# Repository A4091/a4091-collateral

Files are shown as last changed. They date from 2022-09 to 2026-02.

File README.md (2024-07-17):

# A4091 collateral material

This repository contains all the artsy and non-PCB/non-logic/non-software
pieces that went into making the ReAmiga 4091:

## The Box

The original box dimensions are:

| Length | Width | Height |
|---|---|---|
| 43cm | 16cm  | 6.5cm  |
| 16.92" | 6.3"  | 2.56"  |

At least one DKB box out there was confirmed with these dimensions:

| Length | Width | Height |
|---|---|---|
| 39cm | 17cm  | 5cm |

You can find the art work in the `box/` subdirectory. *NOTE:* The first batch
of boxes we had manufactured were 17" x 6.75" x 3.25" as we did not have any
exact measurements to go by.

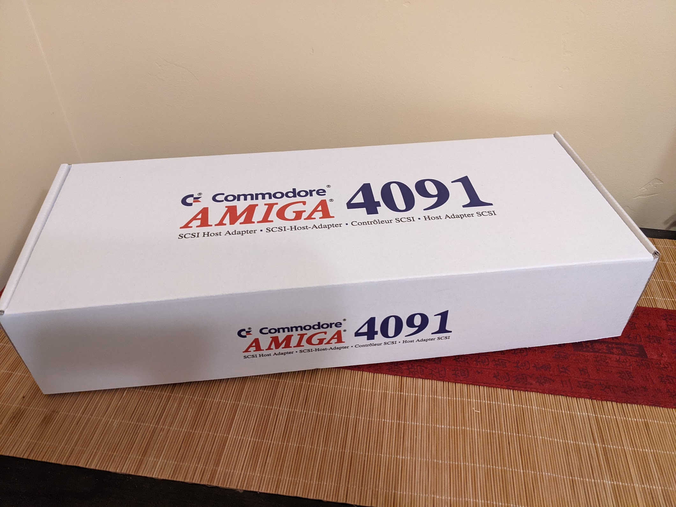
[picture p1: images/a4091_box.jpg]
Box

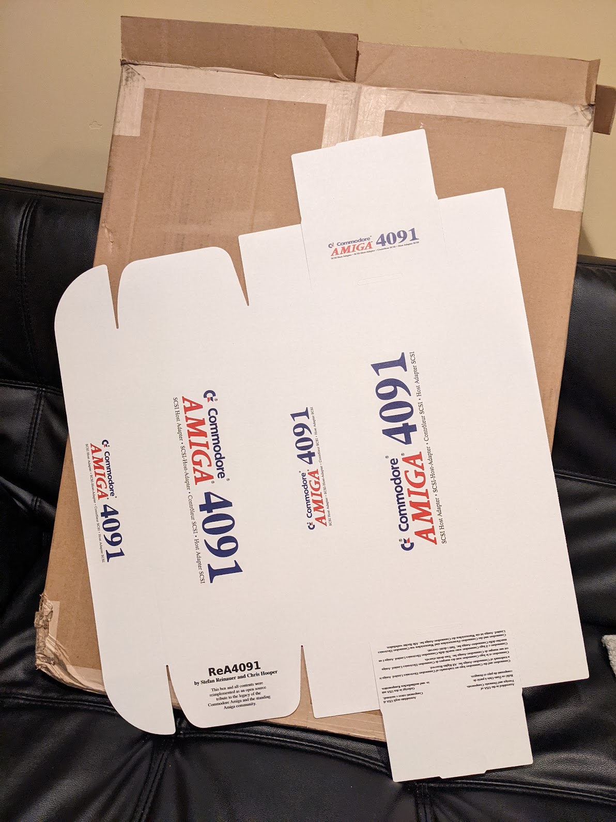
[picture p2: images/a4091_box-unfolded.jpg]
Box Unfolded


## The Manual

The A4091 manual is 5.5" x 7.75" in size. If you get it professionally printed,
it is recommended to use the English only version to keep costs down. If you
are going to print all languages, you will probably need to choose Perfect
bound instead of Stapled bound.

Recommended configuration:
- Size: W: 5.5" H: 7.75"
- Grayscale
- 80lb Satin paper
- 24+4 pages
- Binding: Staple
- Cover: 110lb Satin paper
- Cover: Color
- Cover: Soft Touch Lamination

## Bracket

The metal bracket was designed by Szymon Gosk.

It is recommended to laser cut the bracket, but you will need the appropriate
equipment to perform the narrow dual bend that prevents the metal from making
contact with the connectors on the back of the card. Additionally it is
recommended to apply some foil into the double bend.

Feel free to [contact us](mailto:a4091@amiga.technology) if you need a bracket.
We might still have some left.

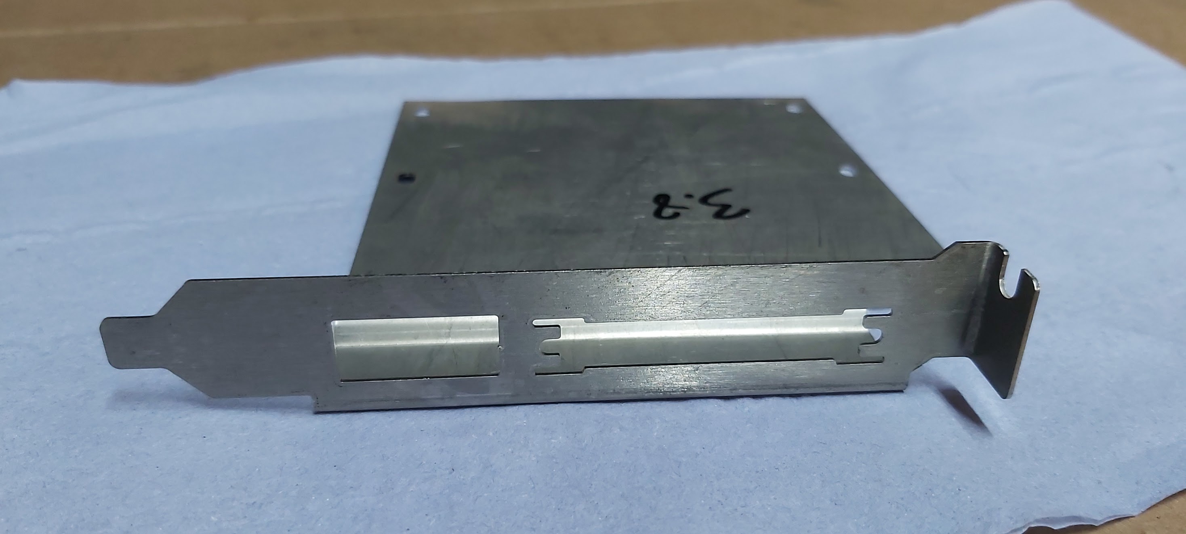
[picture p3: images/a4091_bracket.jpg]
Bracket


## Disk Labels

While the disk content is part of the a4091-software package, you can find a
set of disk labels here.

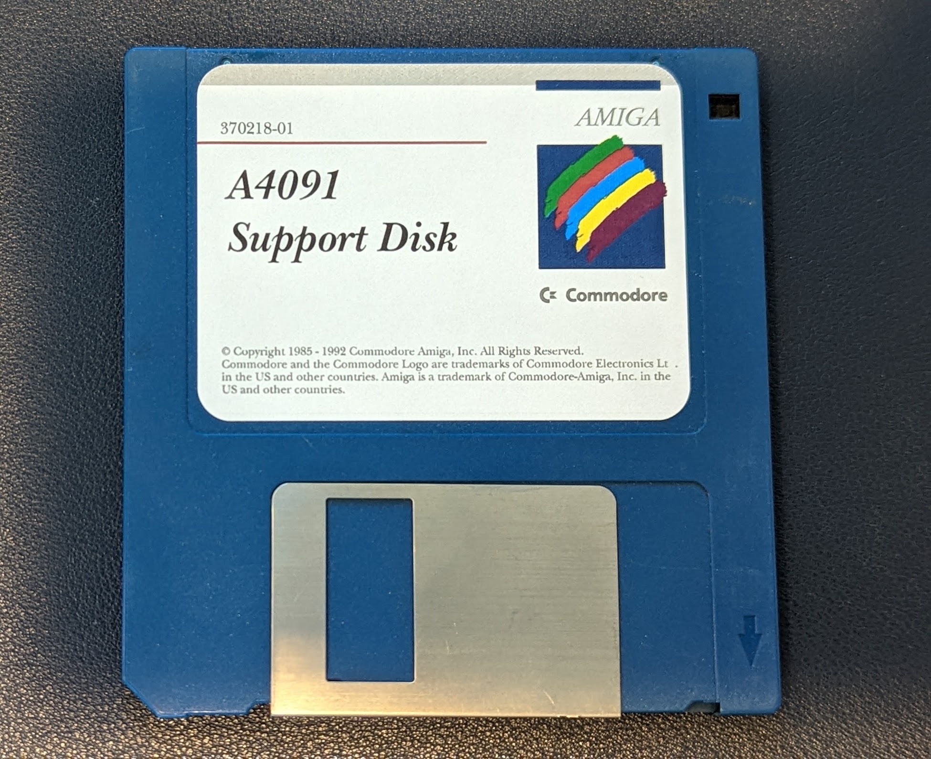
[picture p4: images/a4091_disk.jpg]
Disk


## Amiga 3000 LED adapter

A small adapter that lets you connect your A4091 to your A3000 LEDs. Gerbers
and KiCAD files included.

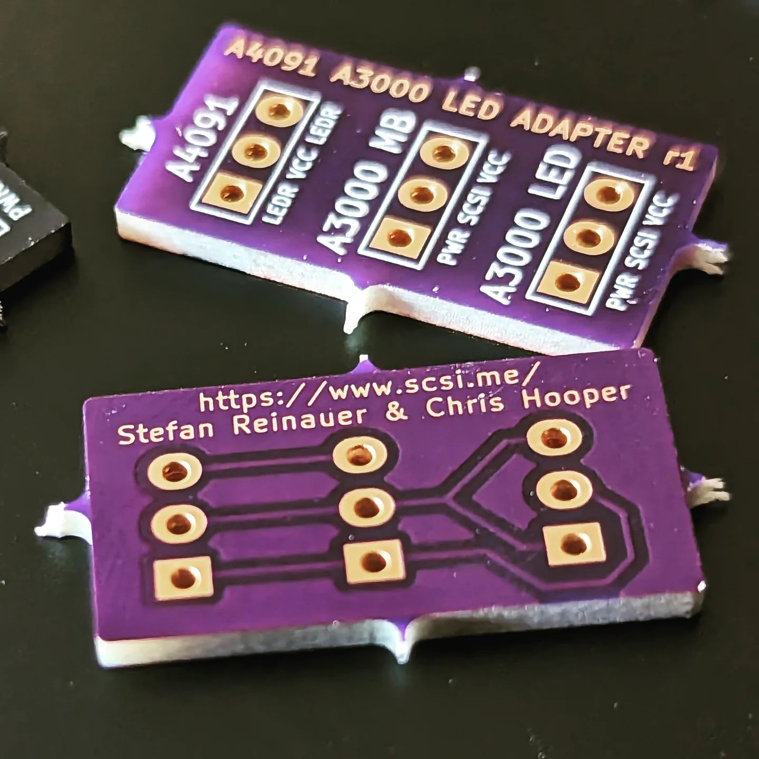
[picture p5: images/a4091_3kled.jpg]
LED adapter


## Miscellaneous

There are a couple of 3d-printable designs available to accompany the A4091
SCSI controller.

- An enclosure for the A4091 Terminator. This enclosure comes in two versions,
  Version v1 is optimized for printing on an FDM printer as the text on the lid
  is recessed. Version v2 has embossed text and is better printed on a Resin
  printer.

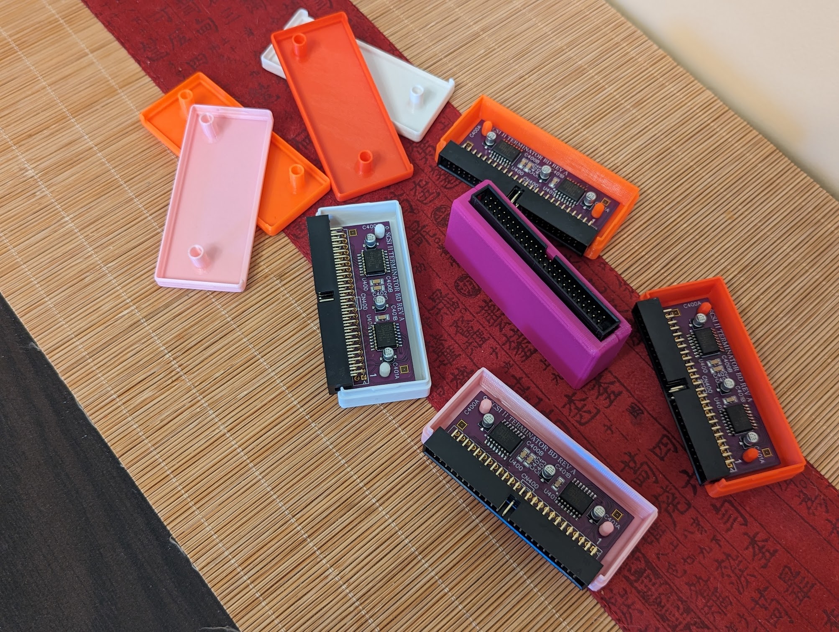
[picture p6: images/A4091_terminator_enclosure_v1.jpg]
A4091 Terminator enclosure v1
  
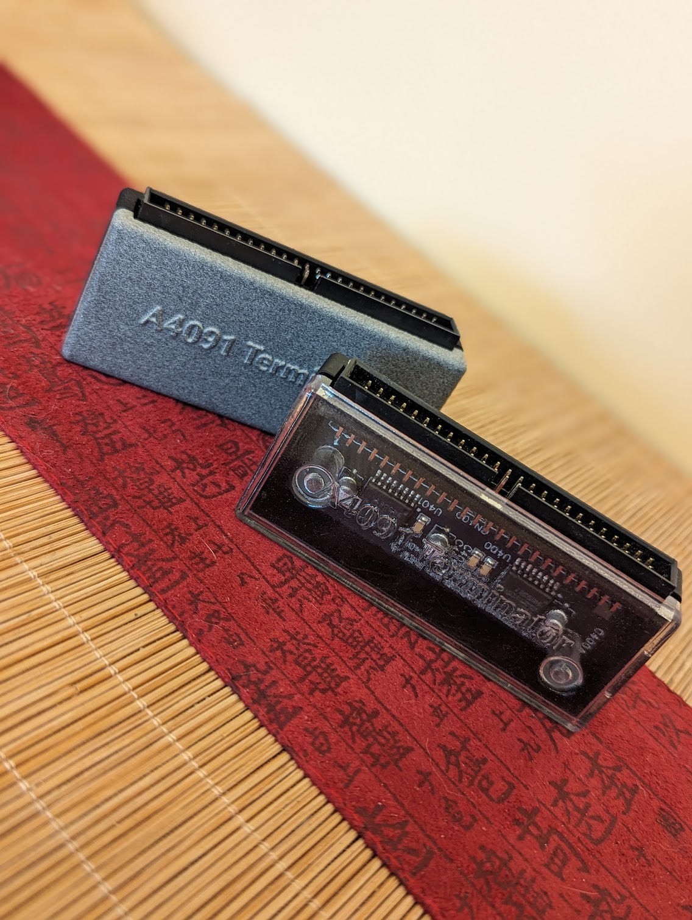
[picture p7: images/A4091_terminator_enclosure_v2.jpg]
A4091 Terminator enclosure v2
  

- Szymon Gosk made a A4091 themed SCSI2SD adapter that you can 3d print
  yourself.

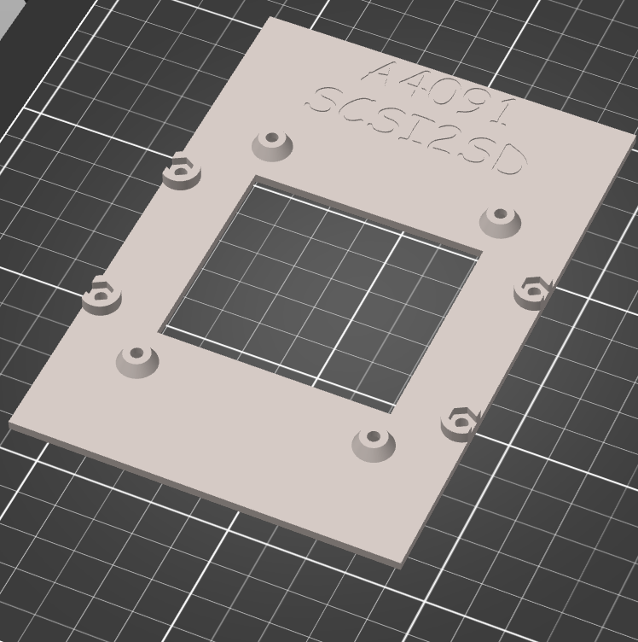
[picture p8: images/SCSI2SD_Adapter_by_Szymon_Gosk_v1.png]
SCSI2SD


- There is also a newer version with a slightly different design that works
well with ZuluSCSI too.

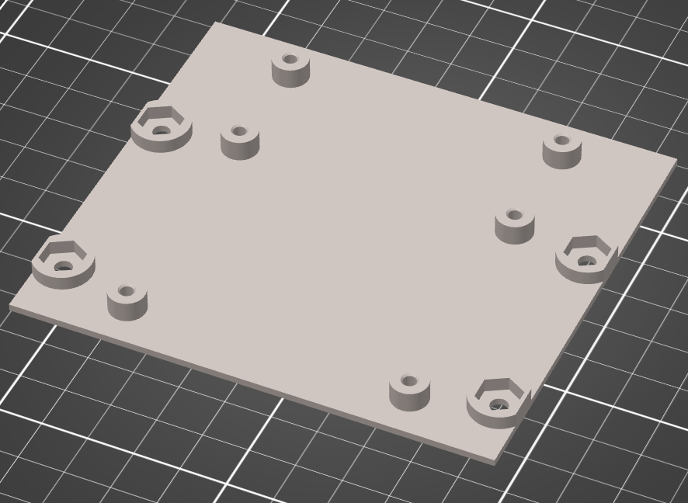
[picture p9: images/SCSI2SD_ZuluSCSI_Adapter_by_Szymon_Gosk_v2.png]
SCSI2SD

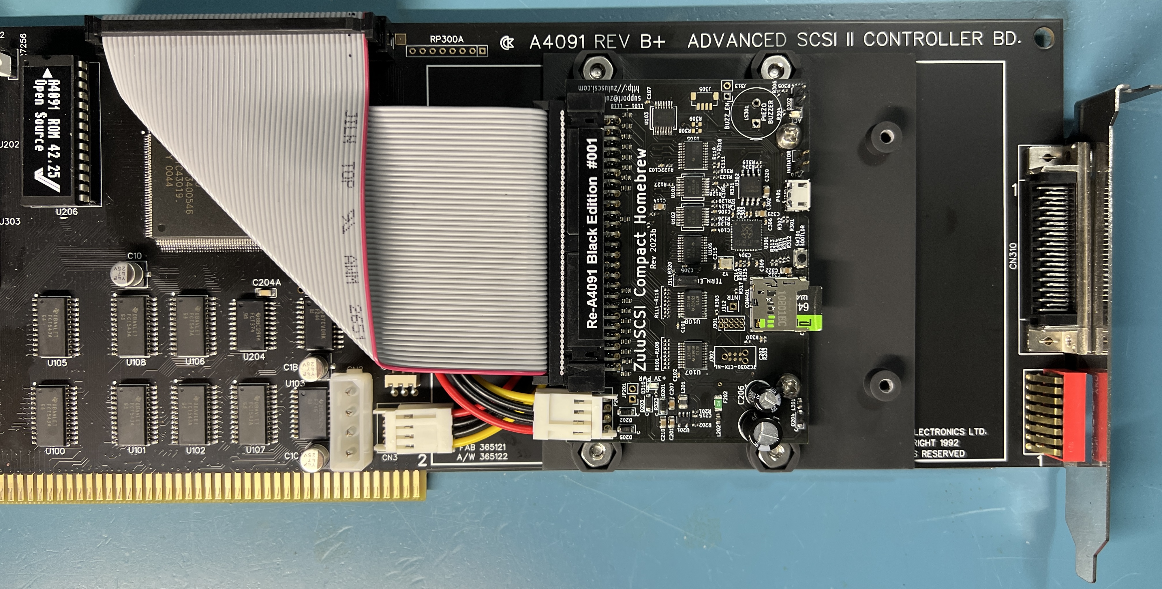
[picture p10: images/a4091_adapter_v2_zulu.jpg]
Adapter Zulu

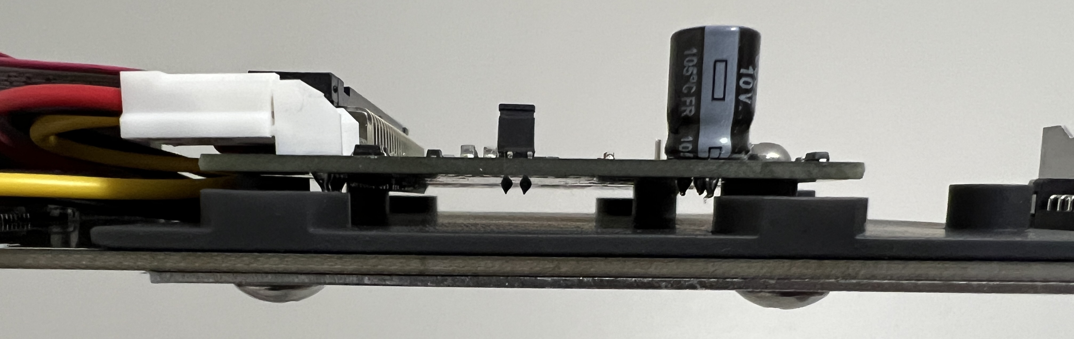
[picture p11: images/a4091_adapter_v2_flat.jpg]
Adapter Side


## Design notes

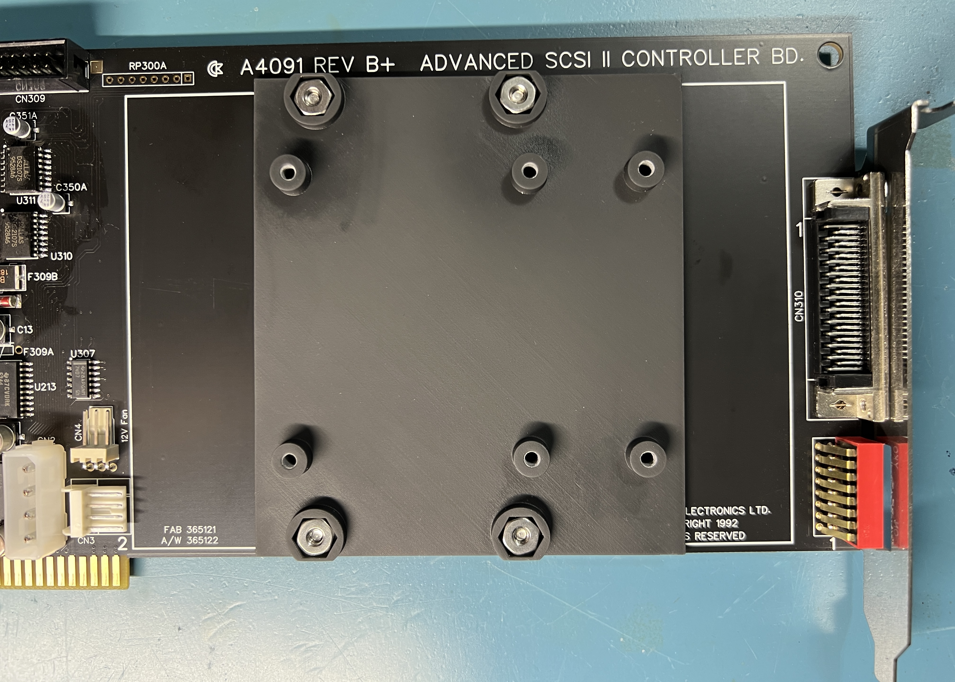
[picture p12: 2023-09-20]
images/a4091_adapter_v2.jpg

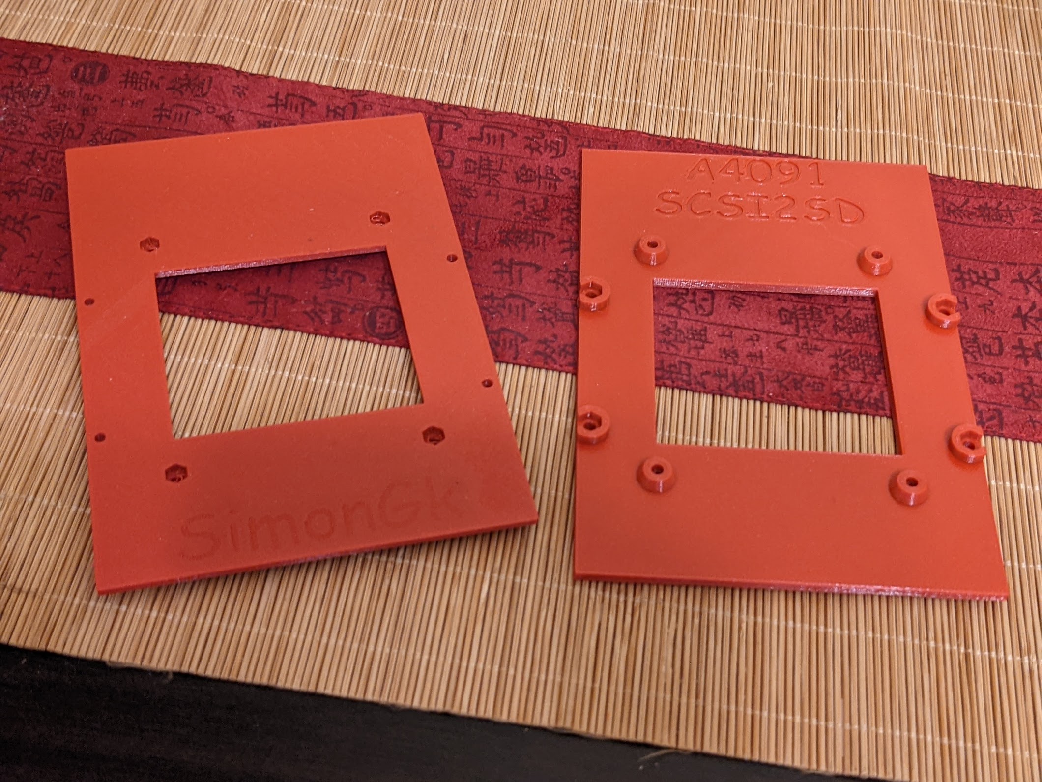
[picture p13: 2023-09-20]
images/a4091_adapter_v1.jpg

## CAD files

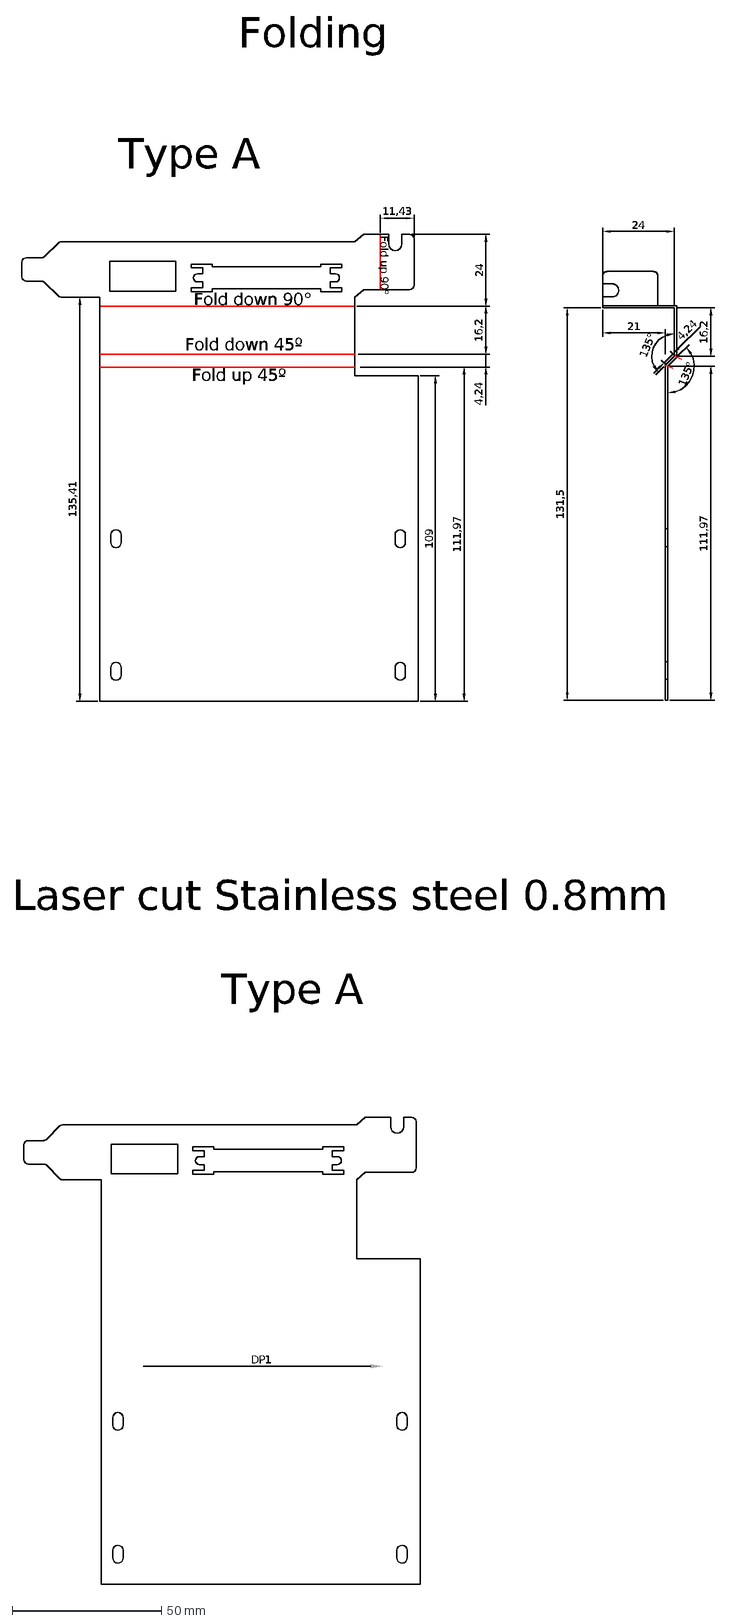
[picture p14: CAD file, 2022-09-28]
bracket/ReA4091_bracket_by_Szymon_Gosk_.dxf
Type A
Laser cut Stainless steel 0.8mm
Folding
24
21
111,97
16,2
135°
Fold up 90°
11,43
131,5
4,24
Fold down 90°
Fold down 45º
Fold up 45º
135,41
109
DP1

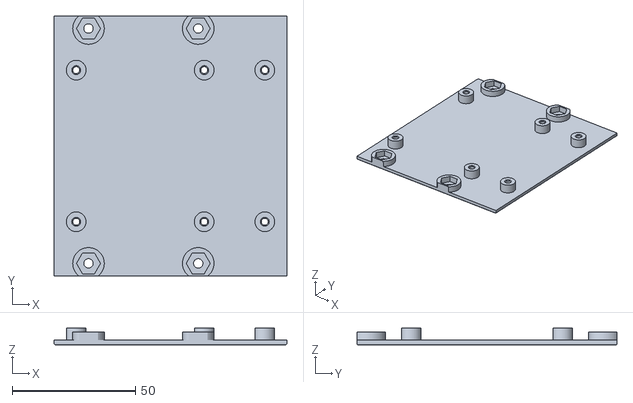
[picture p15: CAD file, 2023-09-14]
misc/SCSI2SD_ZuluSCSI_Adapter_by_Szymon_Gosk_v2.stl
94.5 x 105.4 x 6.80

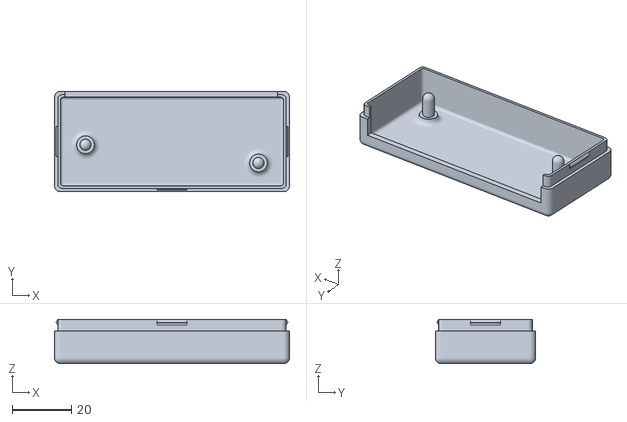
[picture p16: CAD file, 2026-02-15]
misc/Terminator/A4091_terminator_base_resin_round.stl
79.6 x 34.0 x 15.0

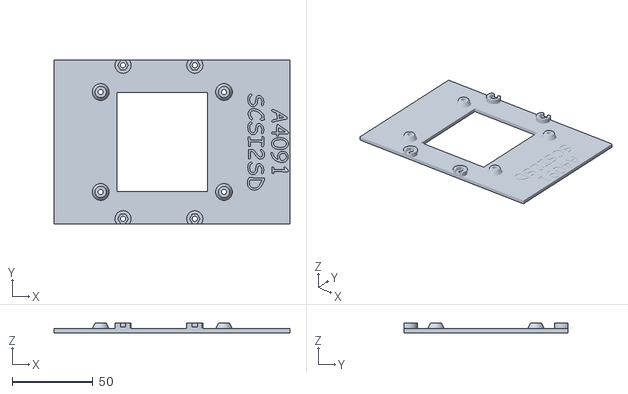
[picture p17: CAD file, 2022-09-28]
misc/SCSI2SD_Adapter_by_Szymon_Gosk_v1.stl
146.4 x 101.6 x 6.00

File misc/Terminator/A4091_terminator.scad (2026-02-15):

// Yet Another Parameterized Projectbox generator
//
//  This is a box for the A4091 active terminator
//

// Label depth: positive = debossed/engraved (FDM), negative = embossed/raised (resin/SLA)
// Override from command line: 0.1 for FDM, -0.4 for resin/SLA
labelDepthVal = -0.4;

// Label text (override from command line for different devices)
labelText = "A4091 Terminator";

include <../YAPP_Box/YAPPgenerator_v3.scad>

//-- which part(s) do you want to print?
printBaseShell        = true;
printLidShell         = true;
printSwitchExtenders  = false;

//-- pcb dimensions -- very important!!!
pcbLength           = 69.6; // Front to back
pcbWidth            = 24; // Side to side
pcbThickness        = 2.2;
                            
//-- padding between pcb and inside wall
paddingFront        = 3;
paddingBack         = 3;
paddingRight        = 3;
paddingLeft         = 3;

//-- Edit these parameters for your own box dimensions
wallThickness       = 2.0;
basePlaneThickness  = 2.0;
lidPlaneThickness   = 2.0;

//-- Total height of box = lidPlaneThickness 
//                       + lidWallHeight 
//--                     + baseWallHeight 
//                       + basePlaneThickness
//-- space between pcb and lidPlane :=
//--      (bottonWallHeight+lidWallHeight) - (standoffHeight+pcbThickness)
baseWallHeight      = 13;
lidWallHeight       = 2;

//-- ridge where base and lid off box can overlap
//-- Make sure this isn't less than lidWallHeight
ridgeHeight         = 4.0;
ridgeSlack          = 0.3;
roundRadius         = 2.0;

//-- Box edge style (added in YAPP v3.2)
//--   0 = all edges rounded (original v30 look)
//--   1 = all edges square
//--   2 = all edges chamfered
//--   3 = square top/bottom, rounded vertical
//--   4 = square top/bottom, chamfered vertical
//--   5 = chamfered top/bottom, rounded vertical
boxType             = 5;

//-- How much the PCB needs to be raised from the base
//-- to leave room for solderings and whatnot
standoffHeight      = 2.0;  //-- used only for pushButton and showPCB
standoffPinDiameter = 3.8;
standoffHoleSlack   = 0.4;
standoffDiameter    = 6.0;

//-- C O N T R O L -------------//-> Default ---------
showSideBySide      = true;     //-> true
previewQuality      = 5;        //-> from 1 to 32, Default = 5
renderQuality       = 32;       //-> from 1 to 32, Default = 8
onLidGap            = 0;
shiftLid            = 5;
colorLid            = "YellowGreen";   
alphaLid            = 1;//0.25;   
colorBase           = "BurlyWood";
alphaBase           = 1;//0.25;
hideLidWalls        = false;    //-> false
hideBaseWalls       = false;    //-> false
showOrientation     = true;
showPCB             = false;
showSwitches        = false;
showPCBmarkers      = false;
showShellZero       = false;
showCenterMarkers   = false;
inspectX            = 0;        //-> 0=none (>0 from back)
inspectY            = 0;        //-> 0=none (>0 from right)
inspectXfromBack    = false;    // View from the inspection cut foreward
inspectYfromLeft    = true;     // View from the inspection cut to the right
inspectZfromTop     = true;
//-- C O N T R O L ---------------------------------------

//===================================================================
// *** PCB Supports ***
// Pin and Socket standoffs 
//-------------------------------------------------------------------
//  Default origin =  yappCoordPCB : pcb[0,0,0]
//
//  Parameters:
//   Required:
//    (0) = posx
//    (1) = posy
//   Optional:
//    (2) = Height to bottom of PCB : Default = standoffHeight
//    (3) = PCB Gap : Default = -1 : Default for yappCoordPCB=pcbThickness, yappCoordBox=0
//    (4) = standoffDiameter    Default = standoffDiameter;
//    (5) = standoffPinDiameter Default = standoffPinDiameter;
//    (6) = standoffHoleSlack   Default = standoffHoleSlack;
//    (7) = filletRadius (0 = auto size)
//    (n) = { <yappBoth> | yappLidOnly | yappBaseOnly }
//    (n) = { yappHole, <yappPin> } // Baseplate support treatment
//    (n) = { <yappAllCorners> | yappFrontLeft | yappFrontRight | yappBackLeft | yappBackRight }
//    (n) = { yappCoordBox, <yappCoordPCB> }  
//    (n) = { yappNoFillet }
//-------------------------------------------------------------------

pcbStands = [
  [5.5,4.735,  yappBoth, yappPin, yappFrontLeft]
 ,[64.1,10.9,  yappPin, yappBoth, yappFrontLeft]
];


//===================================================================
//  *** Cutouts ***
//    There are 6 cutouts one for each surface:
//      cutoutsBase, cutoutsLid, cutoutsFront, cutoutsBack, cutoutsLeft, cutoutsRight
//-------------------------------------------------------------------
//  Default origin = yappCoordBox: box[0,0,0]
//
//                        Required                Not Used        Note
//                      +-----------------------+---------------+------------------------------------
//  yappRectangle       | width, length         | radius        |
//  yappCircle          | radius                | width, length |
//  yappRoundedRect     | width, length, radius |               |     
//  yappCircleWithFlats | width, radius         | length        | length=distance between flats
//  yappCircleWithKey   | width, length, radius |               | width = key width length=key depth
//  yappPolygon         | width, length         | radius        | yappPolygonDef object must be provided
//
//  Parameters:
//   Required:
//    (0) = from Back
//    (1) = from Left
//    (2) = width
//    (3) = length
//    (4) = radius
//    (5) = shape : {yappRectangle | yappCircle | yappPolygon | yappRoundedRect | yappCircleWithFlats | yappCircleWithKey}
//  Optional:
//    (6) = depth : Default = 0/Auto : 0 = Auto (plane thickness)
//    (7) = angle : Default = 0
//    (n) = { yappPolygonDef } : Required if shape = yappPolygon specified -
//    (n) = { yappMaskDef } : If a yappMaskDef object is added it will be used as a mask for the cutout.
//    (n) = { [yappMaskDef, hOffset, vOffset, rotations] } : If a list for a mask is added it will be used as a mask for the cutout. With the Rotation and offsets applied. THis can be used to fine tune the mask placement in the opening.
//    (n) = { <yappCoordBox> | yappCoordPCB }
//    (n) = { <yappOrigin>, yappCenter }
//  (n) = { yappLeftOrigin, <yappGlobalOrigin> } // Only affects Top, Back and Right Faces
//-------------------------------------------------------------------

cutoutsRight =  
[
  // Cutout for SCSI IDC50
 [34.5, 6-pcbThickness ,72.0,10.1, 0, yappRectangle , yappCenter, yappCoordPCB] 

 ];


//===================================================================
//  *** Snap Joins ***
//-------------------------------------------------------------------
//  Default origin = yappCoordBox: box[0,0,0]
//
//  Parameters:
//   Required:
//    (0) = posx | posy
//    (1) = width
//    (n) = yappLeft / yappRight / yappFront / yappBack (one or more)
//   Optional:
//    (n) = { <yappOrigin> | yappCenter }
//    (n) = { yappSymmetric }
//    (n) = { yappRectangle } == Make a diamond shape snap
//-------------------------------------------------------------------

snapJoins =   
[
  [(shellWidth/2),     10, yappFront,yappBack, yappCenter, yappRectangle]
 ,[(shellLength/2),    10, yappLeft, yappCenter, yappRectangle]
];

labelsPlane =
[
    [shellLength/2, shellWidth/2, 180, labelDepthVal, yappLid, "Optima:style=bold", 5,
     labelText, 0, yappTextLeftToRight, yappTextHAlignCenter, yappTextVAlignCenter ]

];

//---- This is where the magic happens ----
YAPPgenerate();

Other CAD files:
misc/Terminator/A4091_terminator_base_fdm_round.stl

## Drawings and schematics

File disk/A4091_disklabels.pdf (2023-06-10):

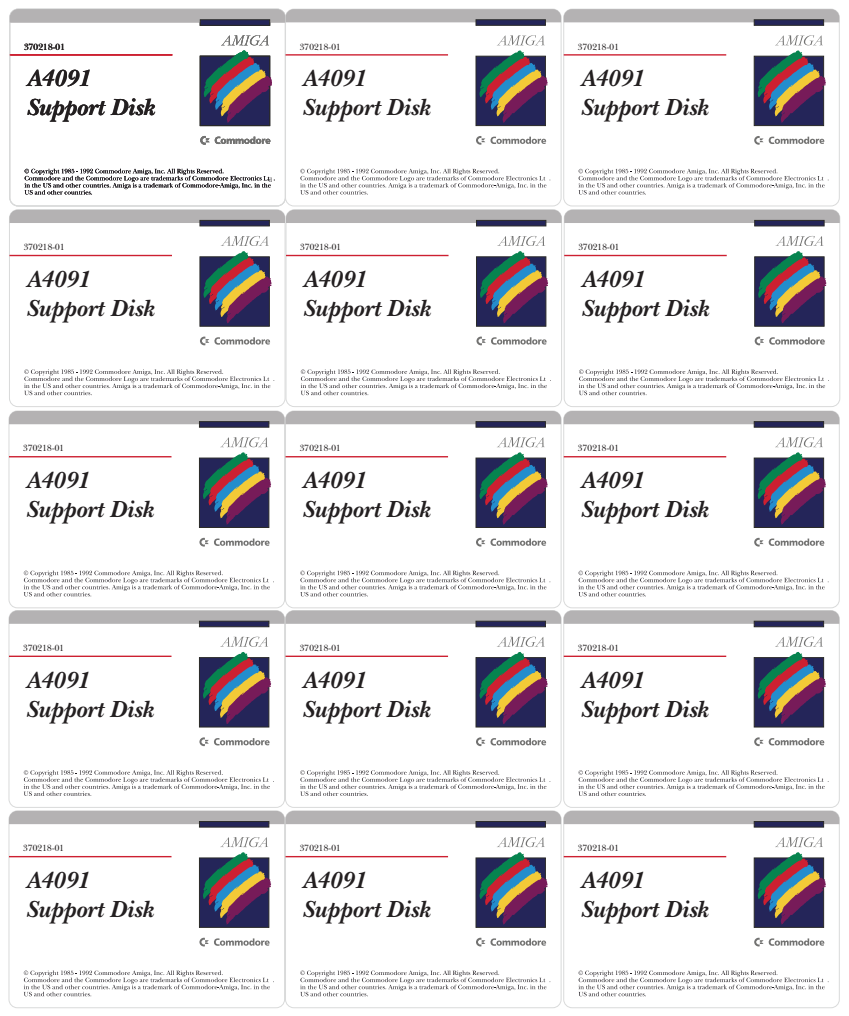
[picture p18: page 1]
370218-01 A4091 Support Disk

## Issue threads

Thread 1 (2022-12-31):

trick for scanning document with way too thin pages

sxpert, 2022-12-31:
insert a black sheet of paper (for example, art paper) between the next pages, this will mask the text on the other side of the page while scanning

reinauer, 2023-09-14:
Thank you for the tip!

Closed 2023-09-14.

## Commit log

2022-09-28 Add metal bracket and SCSI2SD mount by Szymon Gosk
    [ReA4091_bracket_by_Szymon_Gosk_.dxf, SCSI2SD_by_Szymon_Gosk.stl]
2023-09-14 New disk mounting plate for Zulu/SCSI2SD
    Szymon updated the mounting plate to accommodate both full
    size and compact Zulu / SCSI2SD.
    Compact uses 2 screws and the back posts closer to SCSI connector
    are acting as rest points where PCB sits flat without touching
    any solder points. The posts holding the card is 1 mm higher to
    prevent the card touching the nuts or screws securing the adapter
    to A4091. The hexagons are slightly large for hex nuts, but they
    still work fine.
    [SD2SCSI_ZuluSCSI_Adapter_by_Szymon_Gosk_v2.stl]
2023-09-26 Add A3000 LED adapter
    [A4091_3KLED.kicad_pcb, A4091_3KLED.kicad_sch]
2024-01-09 Rename SCSI2SD adapters by Szymon to have consistent names
    [SCSI2SD_Adapter_by_Szymon_Gosk_v1.stl, SCSI2SD_ZuluSCSI_Adapter_by_Szymon_Gosk_v2.stl]
2024-01-26 Add A4091 terminator enclosure
    and update README.md
    [A4091_terminator_base_v1.stl, A4091_terminator_base_v2.stl, A4091_terminator_lid_v1.stl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]
2024-07-17 Update README to show enclosure pictures
2025-11-30 Add OpenSCAD source for A4091 terminator case
    [A4091_terminator.scad]
2026-02-14 terminator: update enclosure design for YAPP v3 and add build automation
    Update the A4091 terminator case design to work with the YAPP v3
    generator library. The include path is adjusted to point to the new
    library location.
    Rework the lid label to be properly centered on the shell using the
    v3 alignment parameters (yappTextHAlignCenter, yappTextVAlignCenter)
    instead of hardcoded coordinates. Introduce a labelDepth() function
    to control whether labels are debossed (positive, for FDM) or
    embossed (negative, for resin/SLA). The default is set to embossed
    at -0.6mm.
    Add the boxType parameter (defaulting to 0 for rounded edges) and
    enable printing of both base and lid shells by default.
    Add a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
    [A4091_terminator.scad]
2026-02-15 Modernize and automate Terminator case
    New versions of YAPPBox can do chamfered and round boxes, so the
    Makefile is now producing both variants.
    The FDM versions have the lid text slightly debossed, while the
    resin versions emboss the text a bit stronger.
    [A4091_terminator.scad, A4091_terminator_base_fdm_round.stl, A4091_terminator_base_resin_round.stl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]
